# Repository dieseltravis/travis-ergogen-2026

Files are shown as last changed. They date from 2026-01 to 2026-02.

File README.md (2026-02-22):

# Travis's Ergogen v2026
This is a split keyboard with 2 ortholinear symmetrical 40-key halfs made with Ergogen v4. Multiple positions for an i2c OLED and mousewheel encoder. TRRS for connecting halfs, firmware not updated for that yet though.

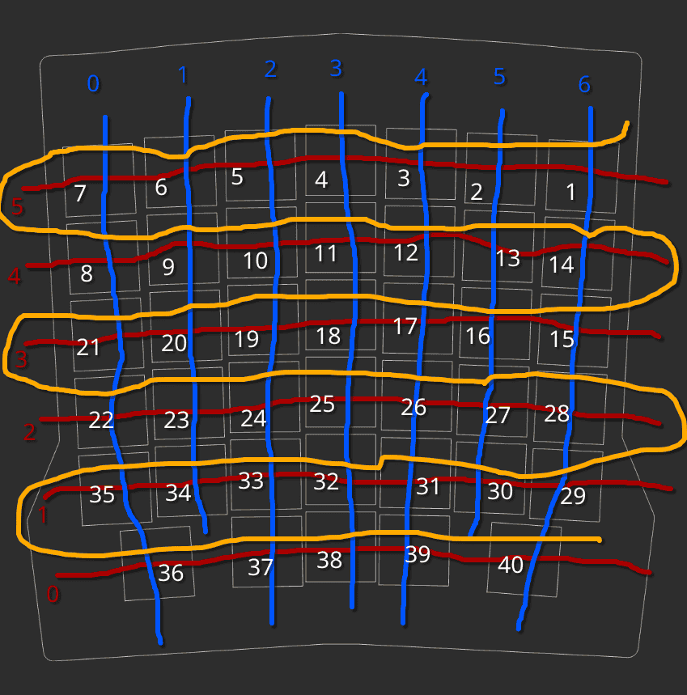
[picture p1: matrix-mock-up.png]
matrix mock up


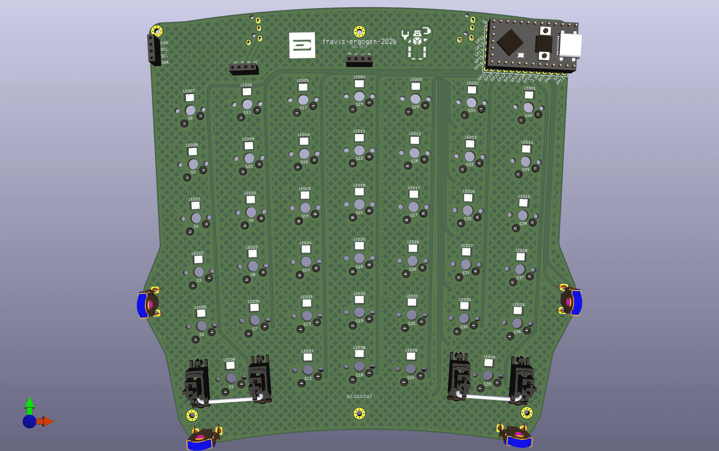
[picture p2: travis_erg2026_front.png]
PCB front


## Parts:

JLCPCB SMD components (40 each per board):
* capacitor C710467
* diode C7420318
* RGB LED C5378731
* MX C41430893

Other parts:
* MCU: RP2040 Community Edition
* capacitor 6.3V 1000uF
* resistors 510k ohm (2 per board)
* 2u stabilizers (2 per board)
* TRRS PJ-320A jacks (2 per board if connecting)
* mousewheel encoder (like Alps-EC10E1220501)
* OLED i2c
* MX switches (40 per board)
* low-profile sockets/pins for MCU & OLED

## References:
My previous ergogen abominations:
* [travis-ergogen-numpad](https://github.com/dieseltravis/travis-ergogen-numpad)
* [travis-ergogen-2024](https://github.com/dieseltravis/travis-ergogen-2024)

### Footprints:
* https://github.com/ceoloide/ergogen-footprints
* https://github.com/dieseltravis/ergogen-footprints-travis

## Tips:

### Font used:
```
brew install --cask font-3270-nerd-font
```
https://www.nerdfonts.com/font-downloads

### Routing widths used:
```
"track_widths": [
        0.0,
        0.254,
        0.3556,
        0.508,
        1.27
      ],
```

### For STL arcs
It is buggy, set toJscadScript's maxArcFacet in Ergogen's cases.js, example locations on my machine:
```
./node_modules/ergogen/src/cases.js
~/.local/share/mise/installs/node/24.13.0/lib/node_modules/ergogen/src/cases.js
```
Note: the arcs are *super* glitchy in STLs

### For weird `node\r:` error:
```
find ./node_modules/ -type f -print0 | xargs -0 dos2unix --
```

## TODO:
* ~board: make those weird bottom shapes nicer~
* plate: print a 2u stab test key
    * ~print a top key test to measure for interference with i2c~
* ~i2c: if plate doesn't interfere with bottom ones remove top ones~
    * ~trrs: if top ones are removed, move left trrs to left side~
* case: just use flat one, arcs get too glitchy
* ~routing~
* ~bom: use [kicad-jlcpcb-tools plugin](https://github.com/Bouni/kicad-jlcpcb-tools)~
* ~leds: generate positions~
* ~qmk firmware~
    * ~via support~
* then arrowpad

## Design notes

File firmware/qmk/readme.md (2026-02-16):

# dieseltravis/travis_ergogen_2026

dieseltravis/travis_ergogen_2026

* Keyboard Maintainer: [Travis Hardiman](https://github.com/dieseltravis)
* Hardware Supported: rp2040ce
* Hardware Availability: https://github.com/dieseltravis/travis-ergogen-2026

Make example for this keyboard (after setting up your build environment):

    make dieseltravis/travis_ergogen_2026:default

Flashing example for this keyboard:

    make dieseltravis/travis_ergogen_2026:default:flash

See the [build environment setup](https://docs.qmk.fm/#/getting_started_build_tools) and the [make instructions](https://docs.qmk.fm/#/getting_started_make_guide) for more information. Brand new to QMK? Start with our [Complete Newbs Guide](https://docs.qmk.fm/#/newbs).

## Bootloader

Enter the bootloader in 3 ways:

* **Bootmagic reset**: Hold down the key at (0,0) in the matrix (usually the top left key or Escape) and plug in the keyboard
* **Physical reset button**: Briefly press the button on the back of the PCB - some may have pads you must short instead
* **Keycode in layout**: Press the key mapped to `RESET` if it is available

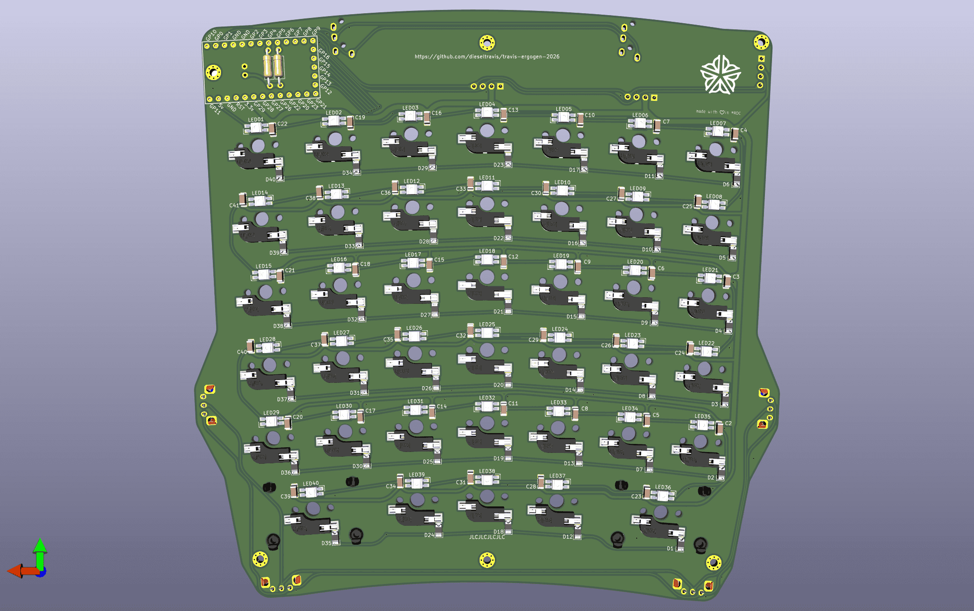
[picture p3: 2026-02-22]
travis_erg2026_back.png

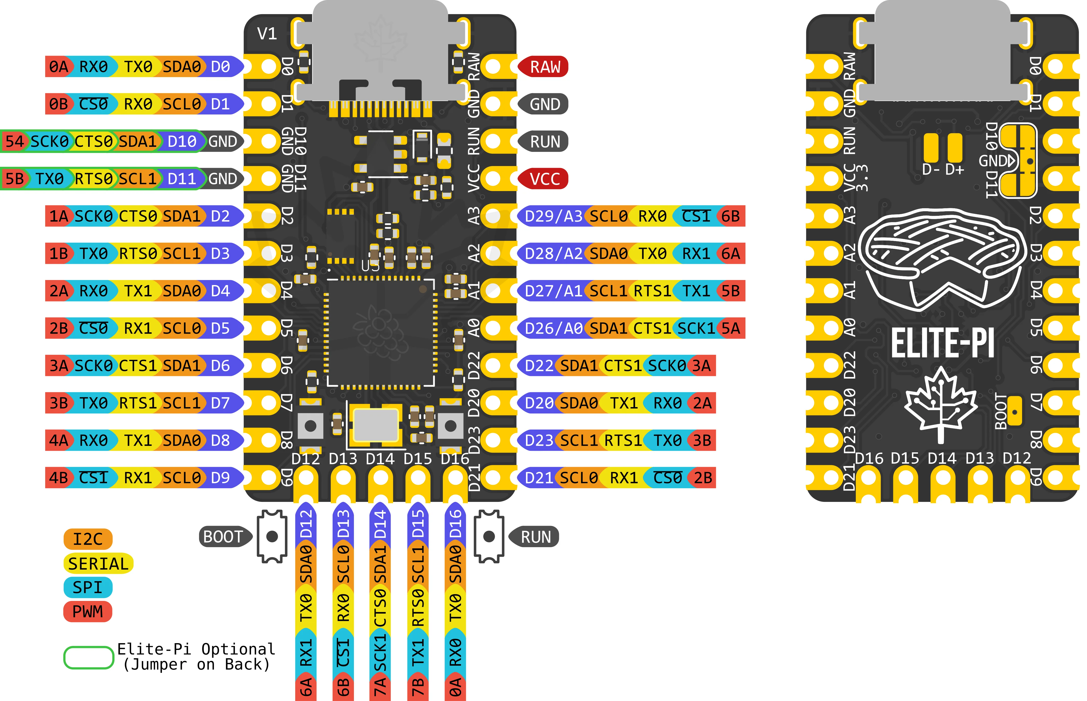
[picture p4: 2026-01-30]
datasheets/mcu-Elite-Pi.png

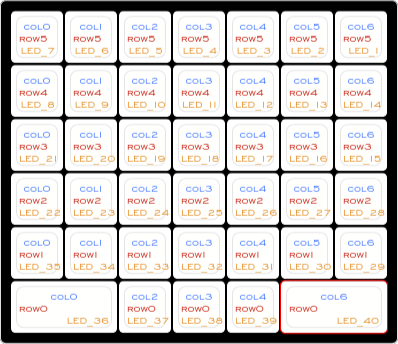
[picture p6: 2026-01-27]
kle/travis-ergogen-2026-matrix.png

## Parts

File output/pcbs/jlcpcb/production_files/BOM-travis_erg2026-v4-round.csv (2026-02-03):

Comment | Designator | Footprint | LCSC | Quantity
C41430893 | S1,S10,S11,S12,S13,S14,S15,S16,S17,S18,S19,S2,S20,S21,S22,S23,S24,S25,S26,S27,S28,S29,S3,S30,S31,S32,S33,S34,S35,S36,S37,S38,S39,S4,S40,S5,S6,S7,S8,S9 | switch_mx | C41430893 | 40
C5378731 | LED01,LED02,LED03,LED04,LED05,LED06,LED07,LED08,LED09,LED10,LED11,LED12,LED13,LED14,LED15,LED16,LED17,LED18,LED19,LED20,LED21,LED22,LED23,LED24,LED25,LED26,LED27,LED28,LED29,LED30,LED31,LED32,LED33,LED34,LED35,LED36,LED37,LED38,LED39,LED40 | led_SK6812mini-e (per-key, single-side) | C5378731 | 40
C710467 | C10,C11,C12,C13,C14,C15,C16,C17,C18,C19,C2,C20,C21,C22,C23,C24,C25,C26,C27,C28,C29,C3,C30,C31,C32,C33,C34,C35,C36,C37,C38,C39,C4,C40,C41,C5,C6,C7,C8,C9 | C_1206_3216Metric | C710467 | 40
C7420318 | D1,D10,D11,D12,D13,D14,D15,D16,D17,D18,D19,D2,D20,D21,D22,D23,D24,D25,D26,D27,D28,D29,D3,D30,D31,D32,D33,D34,D35,D36,D37,D38,D39,D4,D40,D5,D6,D7,D8,D9 | D_1206_3216Metric | C7420318 | 40

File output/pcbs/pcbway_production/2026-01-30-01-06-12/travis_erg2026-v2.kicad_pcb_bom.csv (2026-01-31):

Designator | Quantity | Value | Footprint | Package | MPN | DNP | Mount_Type
C1 | 1 | 6.3V 1000uF | C_Radial_D6.3mm_H11.0mm_P2.50mm |  |  |  | tht
C10, C11, C12, C13, C14, C15, C16, C17, C18, C19, C2, C20, C21, C22, C23, C24, C25, C26, C27, C28, C29, C3, C30, C31, C32, C33, C34, C35, C36, C37, C38, C39, C4, C40, C41, C5, C6, C7, C8, C9 | 40 | C710467 | C_1206_3216Metric |  |  |  | smt
D1, D10, D11, D12, D13, D14, D15, D16, D17, D18, D19, D2, D20, D21, D22, D23, D24, D25, D26, D27, D28, D29, D3, D30, D31, D32, D33, D34, D35, D36, D37, D38, D39, D4, D40, D5, D6, D7, D8, D9 | 40 | C7420318 | D_1206_3216Metric |  |  |  | smt
HOLE1, HOLE2, HOLE3, HOLE4, HOLE5, HOLE6 | 6 |  | MountingHole_2.2mm_M2_Pad_Via |  |  |  | tht
LED01, LED02, LED03, LED04, LED05, LED06, LED07, LED08, LED09, LED10, LED11, LED12, LED13, LED14, LED15, LED16, LED17, LED18, LED19, LED20, LED21, LED22, LED23, LED24, LED25, LED26, LED27, LED28, LED29, LED30, LED31, LED32, LED33, LED34, LED35, LED36, LED37, LED38, LED39, LED40 | 40 | C5378731 | led_SK6812mini-e (per-key, single-side) |  |  |  | smt
MCU1 | 1 | RP2040 Community Edition | RP2040_Pro_Micro |  |  |  | tht
OLED1, OLED2, OLED3, OLED4, OLED5 | 5 | I2C_Breakout | I2C_Breakout |  |  |  | tht
ROT1, ROT2, ROT3, ROT4 | 4 | EC10E1220501 | Alps-EC10E1220501 |  |  |  | tht
S1, S10, S11, S12, S13, S14, S15, S16, S17, S18, S19, S2, S20, S21, S22, S23, S24, S25, S26, S27, S28, S29, S3, S30, S31, S32, S33, S34, S35, S36, S37, S38, S39, S4, S40, S5, S6, S7, S8, S9 | 40 | C41430893 | switch_mx |  |  |  | smt

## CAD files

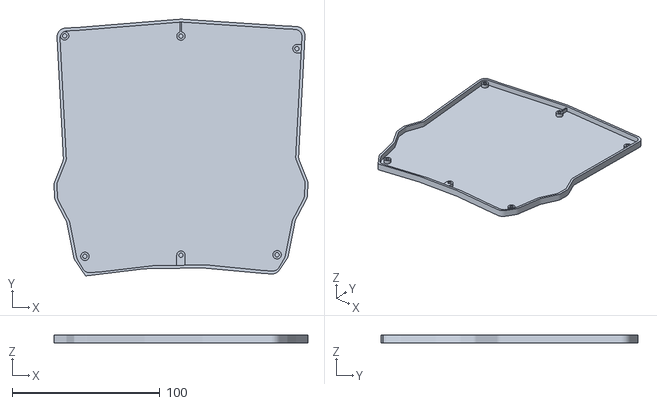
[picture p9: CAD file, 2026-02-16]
output/cases/case.stl
172.1 x 174.0 x 5.60

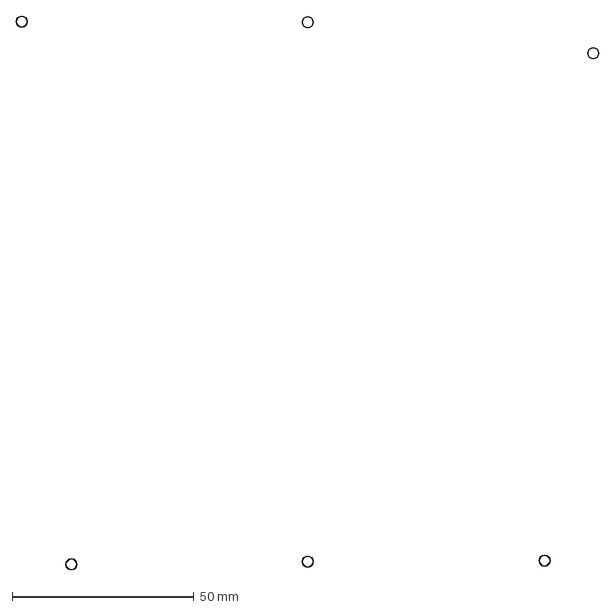
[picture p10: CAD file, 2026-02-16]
output/outlines/_mounting.dxf
160.3 x 152.4 mm

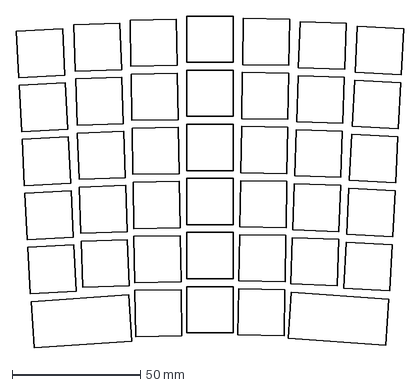
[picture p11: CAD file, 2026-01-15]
output/points/demo.dxf
150.7 x 129.1 mm

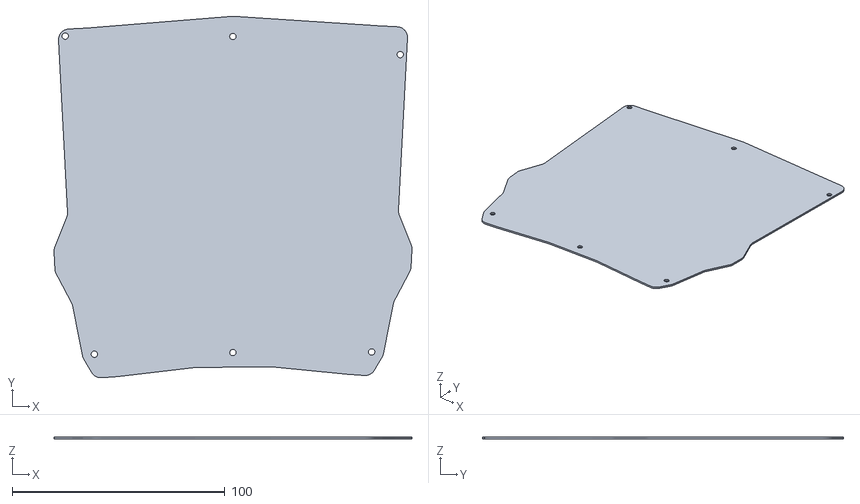
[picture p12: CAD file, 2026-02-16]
output/cases/flatcase.stl
168.1 x 169.8 x 1.00

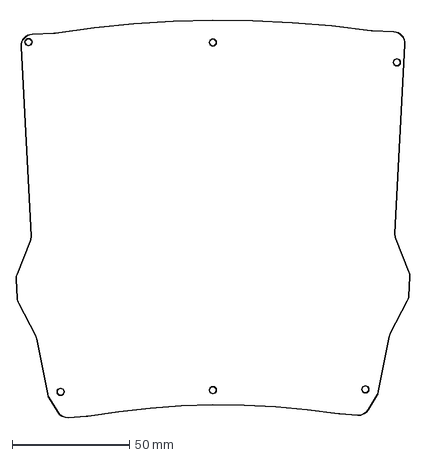
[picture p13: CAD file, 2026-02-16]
output/outlines/flat.dxf
168.2 x 171.7 mm

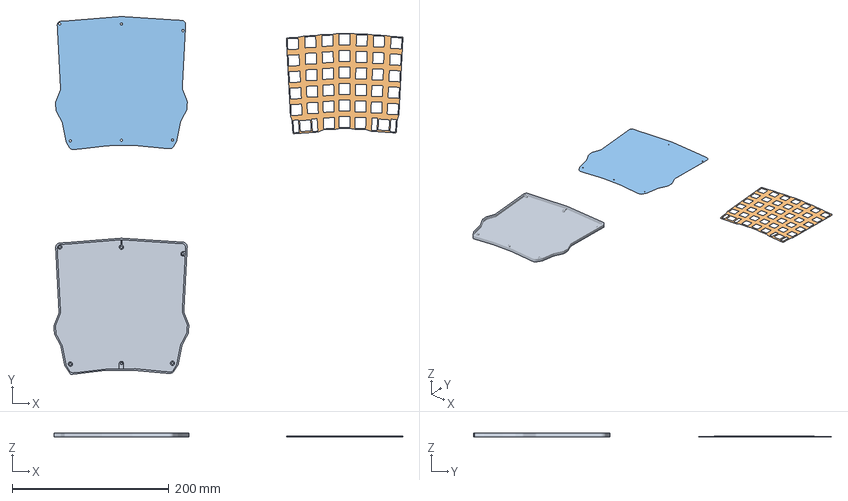
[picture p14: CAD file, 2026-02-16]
output/cases/cases.3mf
445.3 x 456.8 x 5.60 mm
case.stl
plate.stl
flatcase.stl

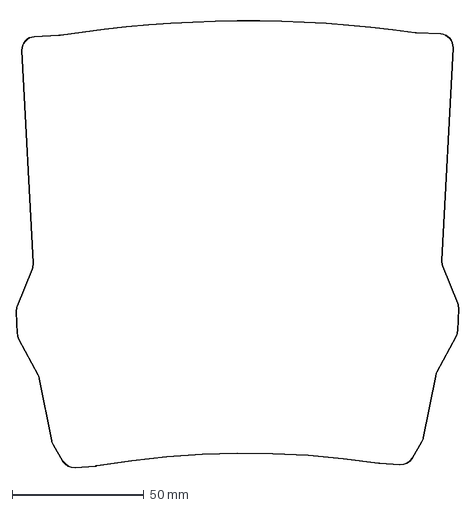
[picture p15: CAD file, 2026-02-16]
output/outlines/board.dxf
168.2 x 171.7 mm

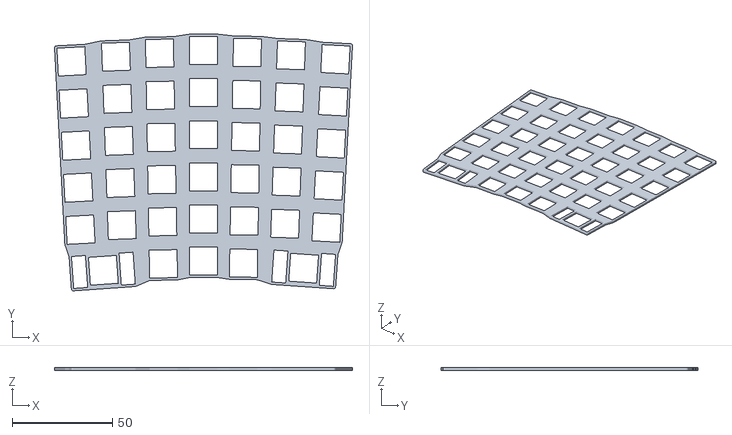
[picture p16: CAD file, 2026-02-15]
output/cases/plate.stl
148.9 x 128.3 x 1.41

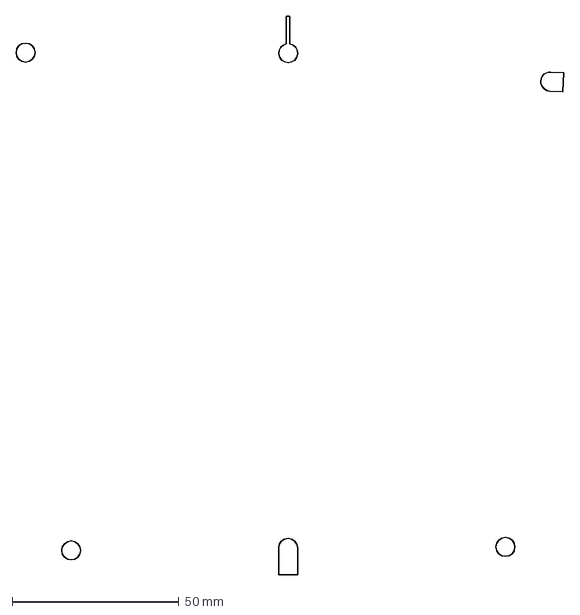
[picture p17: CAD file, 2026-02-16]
output/outlines/_standoff.dxf
164.3 x 167.4 mm

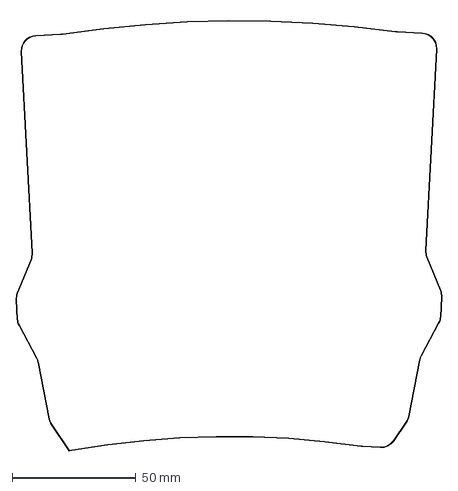
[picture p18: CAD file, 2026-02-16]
output/outlines/_xlboard.dxf
172.2 x 175.8 mm

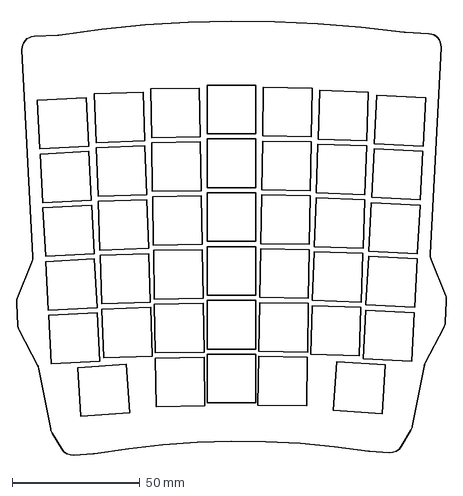
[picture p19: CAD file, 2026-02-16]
output/outlines/_combo.dxf
168.2 x 171.7 mm

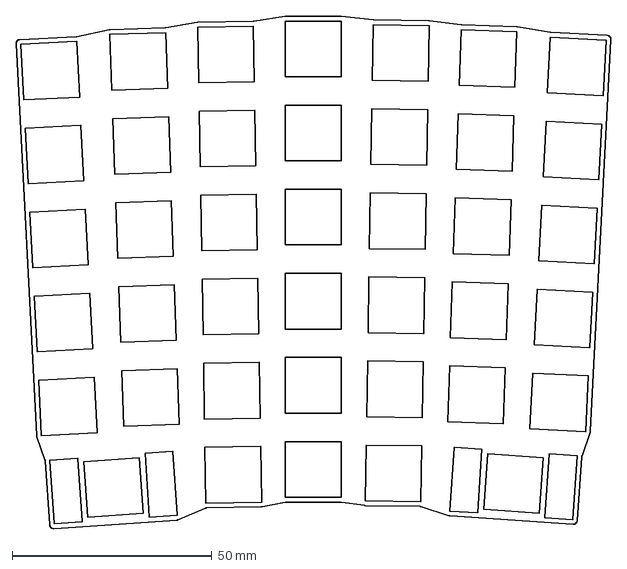
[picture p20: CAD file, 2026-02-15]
output/outlines/_plateholes.dxf
149.0 x 128.3 mm

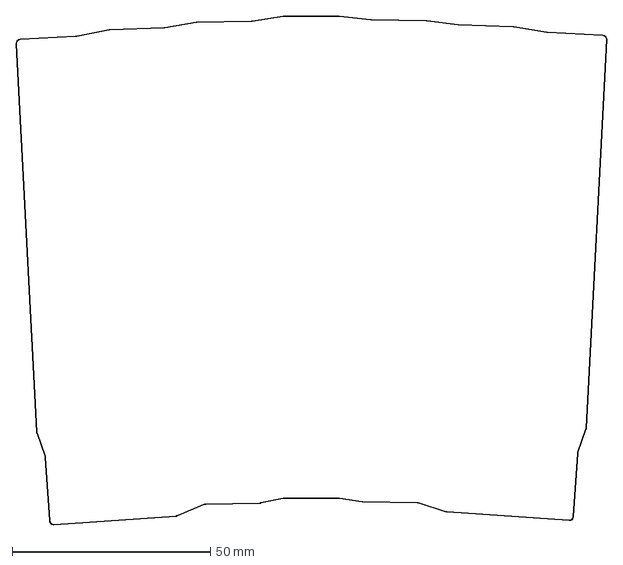
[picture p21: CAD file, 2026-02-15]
output/outlines/_pb.dxf
149.0 x 128.3 mm

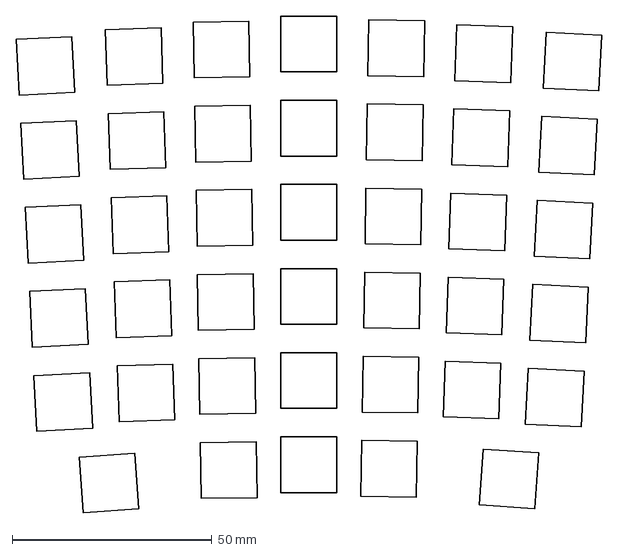
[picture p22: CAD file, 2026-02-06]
output/outlines/_keyholes.dxf
146.5 x 124.2 mm

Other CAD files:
output/outlines/_2u_stabilizer.dxf
output/outlines/_keys.dxf
output/outlines/combo.dxf
output/outlines/mounting.dxf
output/outlines/standoff.dxf
output/outlines/xlboard.dxf

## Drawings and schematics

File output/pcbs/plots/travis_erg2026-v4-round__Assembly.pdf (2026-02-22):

1 | 2 | 3 | 4 | 5 | 6 | 7 | 8

A

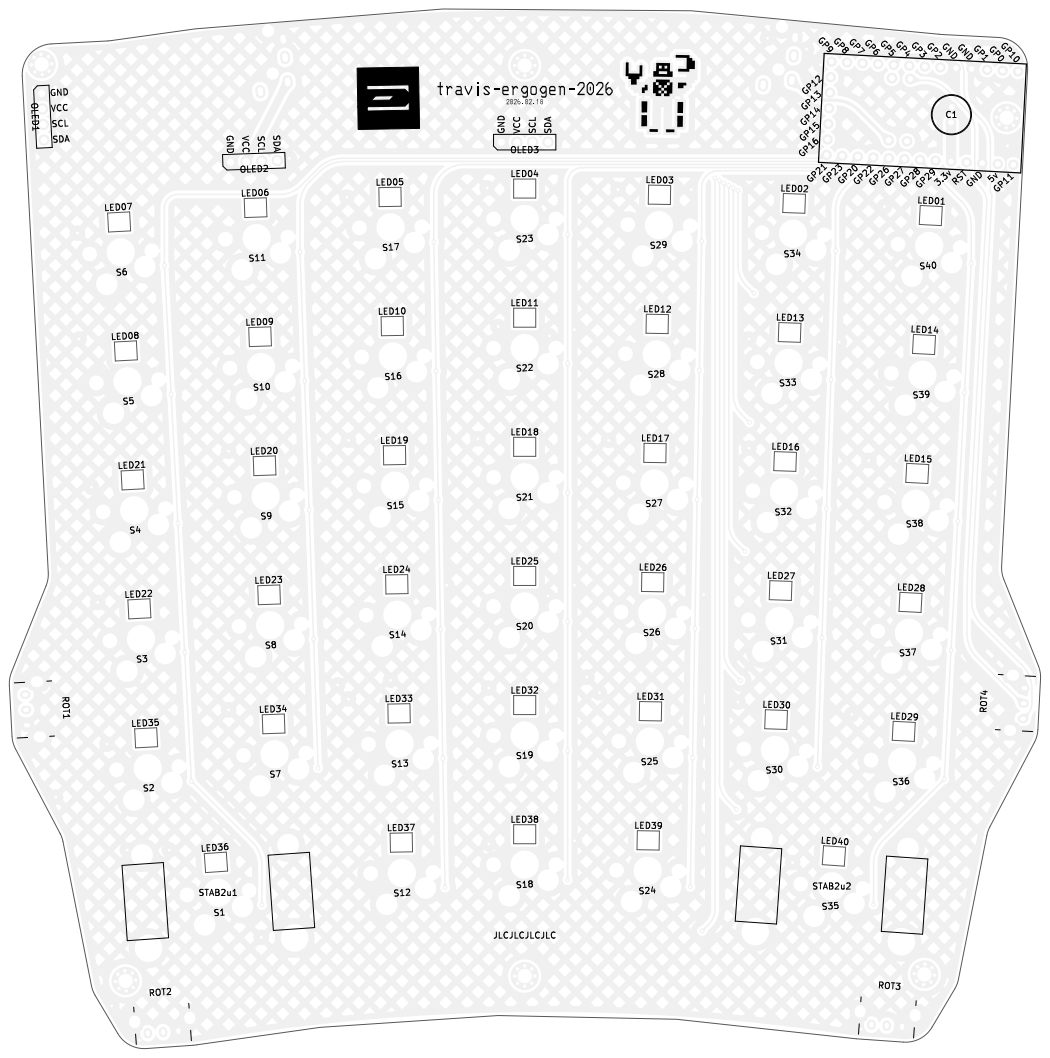
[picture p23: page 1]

SCL SDA GND VCC SCL SDAGND VCC SCL SDA

File: travis_erg2026-v4-round.kicad_pcb Sheet: Black And White TOP
Id: /1 Title: travis_erg2026

1 | 2 | 3 | 4 | 5 | 6 | 7 | 8

A

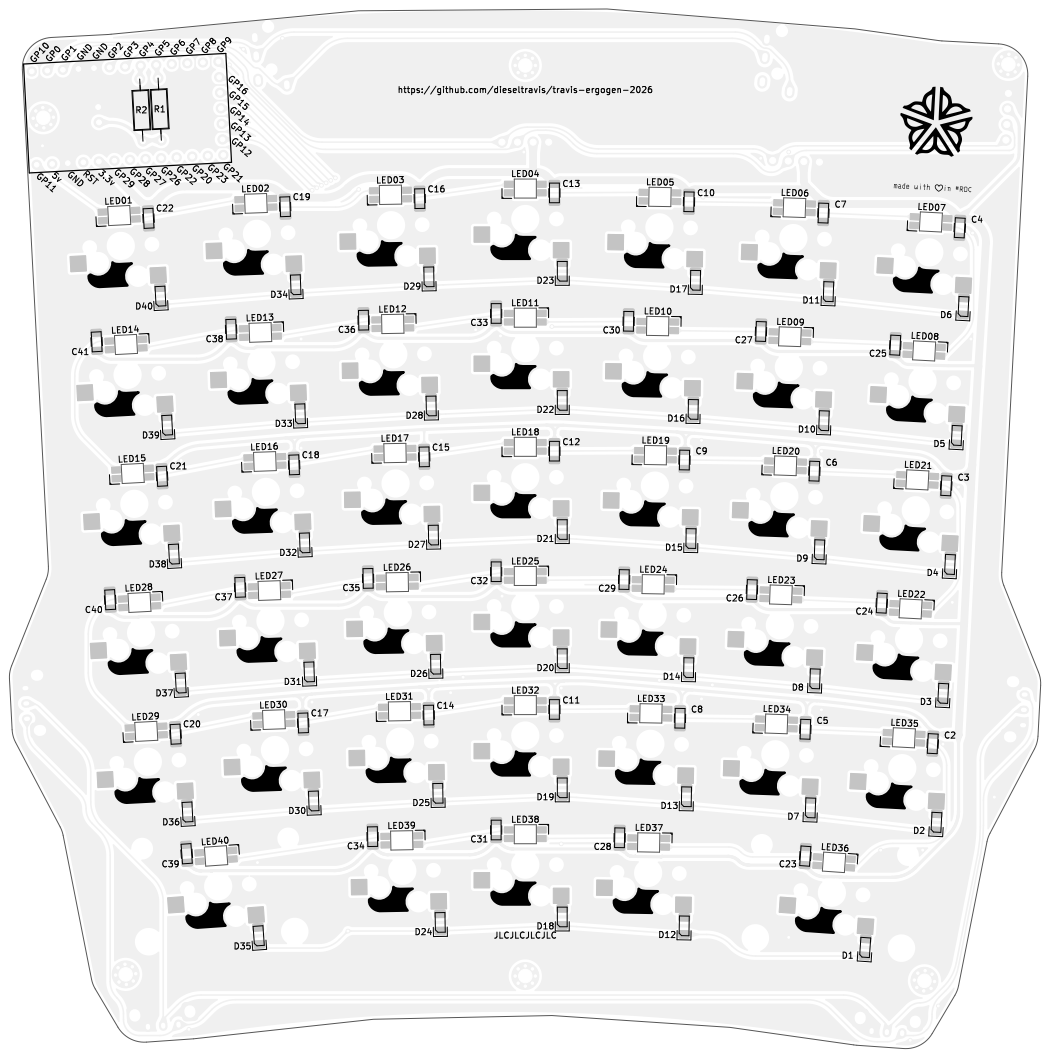
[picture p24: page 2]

https://github.com/dieseltravis/travis-ergogen-2026

File: travis_erg2026-v4-round.kicad_pcb Sheet: Black And White BOT
Id: /1 Title: travis_erg2026

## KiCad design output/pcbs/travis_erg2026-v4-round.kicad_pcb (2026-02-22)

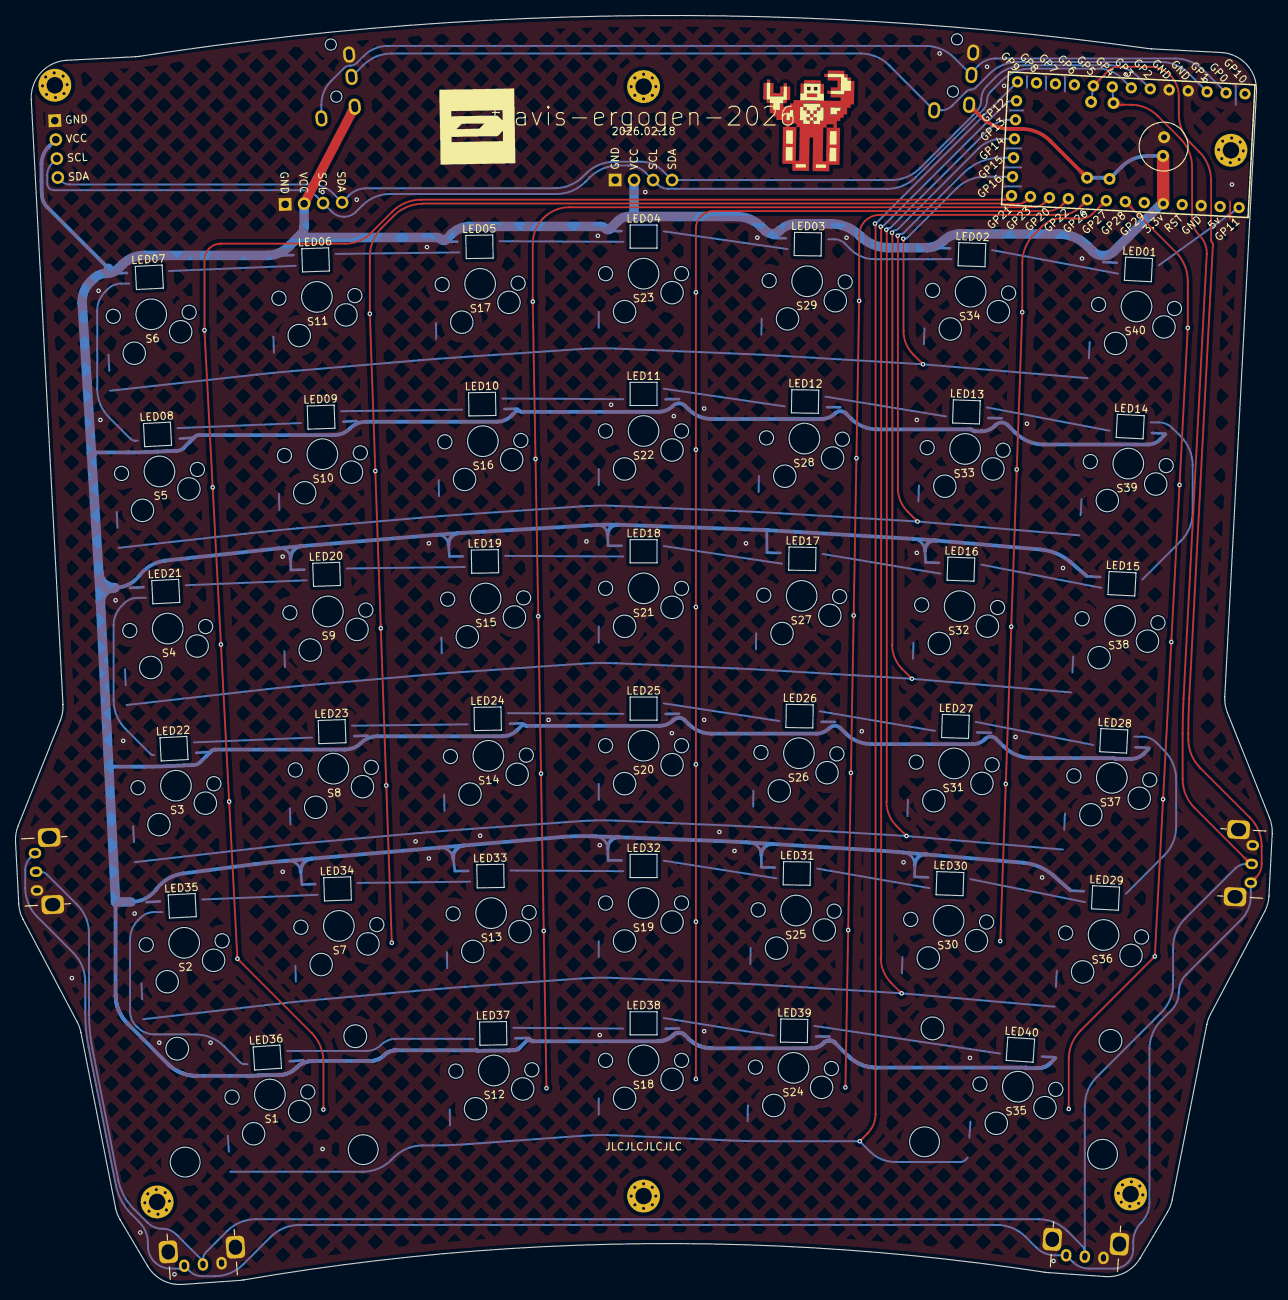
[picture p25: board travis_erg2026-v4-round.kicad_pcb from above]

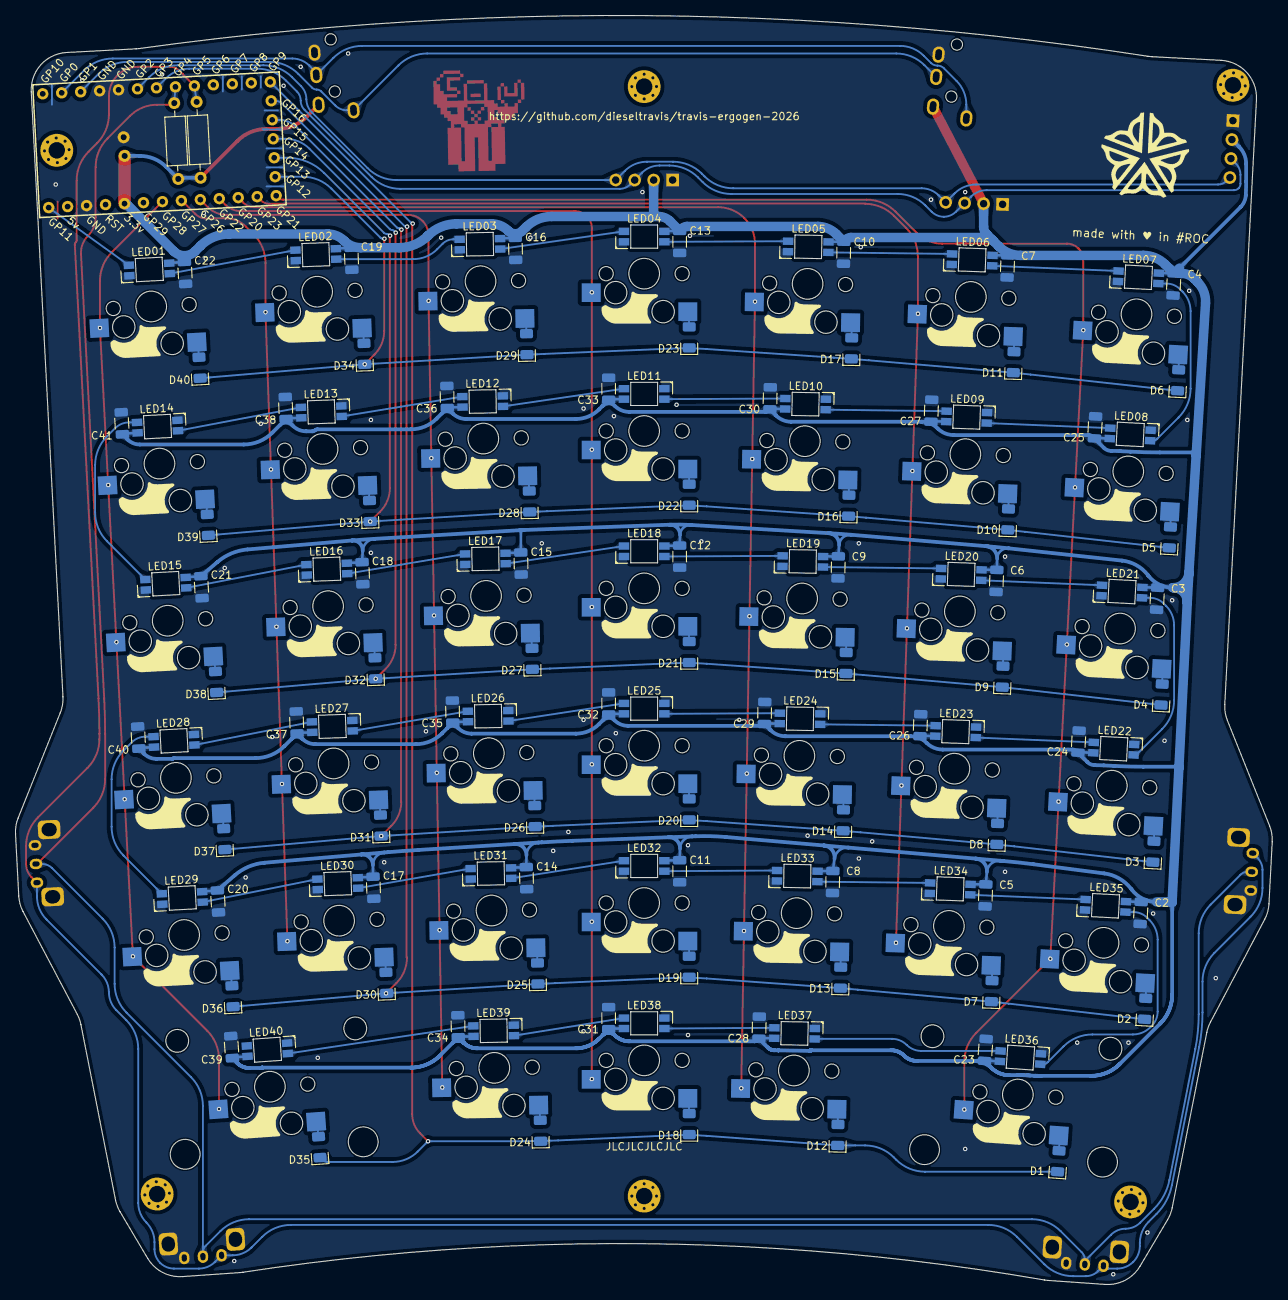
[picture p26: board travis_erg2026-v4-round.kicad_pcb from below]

Board: 2 copper layers, 168.1 x 169.8 mm, 184 parts (163 on the bottom side), 101 nets.

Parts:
C1: 6.3V 1000uF; C_Radial_D6.3mm_H11.0mm_P2.50mm
C2, C3, C4, C5, C6, C7, C8, C9, C10, C11, C12, C13, C14, C15, C16, C17, C18, C19, C20, C21, C22, C23, C24, C25, C26, C27, C28, C29, C30, C31, C32, C33, C34, C35, C36, C37, C38, C39, C40, C41: C710467; C_1206_3216Metric
D1, D2, D3, D4, D5, D6, D7, D8, D9, D10, D11, D12, D13, D14, D15, D16, D17, D18, D19, D20, D21, D22, D23, D24, D25, D26, D27, D28, D29, D30, D31, D32, D33, D34, D35, D36, D37, D38, D39, D40: C7420318; D_1206_3216Metric
HOLE1, HOLE2, HOLE3, HOLE4, HOLE5, HOLE6: MountingHole_2.2mm_M2_Pad_Via
LED01, LED02, LED03, LED04, LED05, LED06, LED07, LED08, LED09, LED10, LED11, LED12, LED13, LED14, LED15, LED16, LED17, LED18, LED19, LED20, LED21, LED22, LED23, LED24, LED25, LED26, LED27, LED28, LED29, LED30, LED31, LED32, LED33, LED34, LED35, LED36, LED37, LED38, LED39, LED40: C5378731; led_SK6812mini-e (per-key, single-side)
LOGO1: utility_ergogen_logo
LOGO2: travis
MCU1: RP2040 Community Edition; RP2040_Pro_Micro
OLED1, OLED2, OLED3: I2C_Breakout
R1, R2: 510k; R_Axial_DIN0207_L6.3mm_D2.5mm_P10.16mm_Horizontal
ROC1: travis
ROT1, ROT2, ROT3, ROT4: EC10E1220501; Alps-EC10E1220501
S1, S2, S3, S4, S5, S6, S7, S8, S9, S10, S11, S12, S13, S14, S15, S16, S17, S18, S19, S20, S21, S22, S23, S24, S25, S26, S27, S28, S29, S30, S31, S32, S33, S34, S35, S36, S37, S38, S39, S40: C41430893; switch_mx
STAB2u1, STAB2u2: Stabilizer_MX_2.00u
TRRS1, TRRS2: trrs_pj320a

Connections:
GND: C1.2, C2.2, C3.2, C4.2, C5.2, C6.2, C7.2, C8.2, C9.2, C10.2, C11.2, C12.2, C13.2, C14.2, C15.2, C16.2, C17.2, C18.2, C19.2, C20.2, C21.2, C22.2, C23.2, C24.2, C25.2, C26.2, C27.2, C28.2, C29.2, C30.2, C31.2, C32.2, C33.2, C34.2, C35.2, C36.2, C37.2, C38.2, C39.2, C40.2, C41.2, LED01.3, LED02.3, LED03.3, LED04.3, LED05.3, LED06.3, LED07.3, LED08.3, LED09.3, LED10.3, LED11.3, LED12.3, LED13.3, LED14.3, LED15.3, LED16.3, LED17.3, LED18.3, LED19.3, LED20.3, LED21.3, LED22.3, LED23.3, LED24.3, LED25.3, LED26.3, LED27.3, LED28.3, LED29.3, LED30.3, LED31.3, LED32.3, LED33.3, LED34.3, LED35.3, LED36.3, LED37.3, LED38.3, LED39.3, LED40.3, MCU1.4, MCU1.5, MCU1.29, OLED1.1, OLED2.1, OLED3.1, ROT1.4, ROT1.C, ROT2.4, ROT2.C, ROT3.4, ROT3.C, ROT4.4, ROT4.C, TRRS1.2, TRRS2.2
LED01: LED01.4, MCU1.31
LED02: LED01.2, LED02.4
LED03: LED02.2, LED03.4
LED04: LED03.2, LED04.4
LED05: LED04.2, LED05.4
LED06: LED05.2, LED06.4
LED07: LED06.2, LED07.4
LED08: LED07.2, LED08.4
LED09: LED08.2, LED09.4
LED10: LED09.2, LED10.4
LED11: LED10.2, LED11.4
LED12: LED11.2, LED12.4
LED13: LED12.2, LED13.4
LED14: LED13.2, LED14.4
LED15: LED14.2, LED15.4
LED16: LED15.2, LED16.4
LED17: LED16.2, LED17.4
LED18: LED17.2, LED18.4
LED19: LED18.2, LED19.4
LED20: LED19.2, LED20.4
LED21: LED20.2, LED21.4
LED22: LED21.2, LED22.4
LED23: LED22.2, LED23.4
LED24: LED23.2, LED24.4
LED25: LED24.2, LED25.4
LED26: LED25.2, LED26.4
LED27: LED26.2, LED27.4
LED28: LED27.2, LED28.4
LED29: LED28.2, LED29.4
LED30: LED29.2, LED30.4
LED31: LED30.2, LED31.4
LED32: LED31.2, LED32.4
LED33: LED32.2, LED33.4
LED34: LED33.2, LED34.4
LED35: LED34.2, LED35.4
LED36: LED35.2, LED36.4
LED37: LED36.2, LED37.4
LED38: LED37.2, LED38.4
LED39: LED38.2, LED39.4
LED40: LED39.2, LED40.4
RX: MCU1.3, TRRS1.3, TRRS2.5
TX: MCU1.2, TRRS1.5, TRRS2.3
VCC: C1.1, C2.1, C3.1, C4.1, C5.1, C6.1, C7.1, C8.1, C9.1, C10.1, C11.1, C12.1, C13.1, C14.1, C15.1, C16.1, C17.1, C18.1, C19.1, C20.1, C21.1, C22.1, C23.1, C24.1, C25.1, C26.1, C27.1, C28.1, C29.1, C30.1, C31.1, C32.1, C33.1, C34.1, C35.1, C36.1, C37.1, C38.1, C39.1, C40.1, C41.1, LED01.1, LED02.1, LED03.1, LED04.1, LED05.1, LED06.1, LED07.1, LED08.1, LED09.1, LED10.1, LED11.1, LED12.1, LED13.1, LED14.1, LED15.1, LED16.1, LED17.1, LED18.1, LED19.1, LED20.1, LED21.1, LED22.1, LED23.1, LED24.1, LED25.1, LED26.1, LED27.1, LED28.1, LED29.1, LED30.1, LED31.1, LED32.1, LED33.1, LED34.1, LED35.1, LED36.1, LED37.1, LED38.1, LED39.1, LED40.1, MCU1.27, OLED1.2, OLED2.2, OLED3.2, R1.1, R2.1, TRRS1.4, TRRS2.4
col0: MCU1.19, S1.1, S2.1, S3.1, S4.1, S5.1, S6.1
col1: MCU1.20, S7.1, S8.1, S9.1, S10.1, S11.1
col2: MCU1.21, S12.1, S13.1, S14.1, S15.1, S16.1, S17.1
col3: MCU1.22, S18.1, S19.1, S20.1, S21.1, S22.1, S23.1
col4: MCU1.23, S24.1, S25.1, S26.1, S27.1, S28.1, S29.1
col5: MCU1.24, S30.1, S31.1, S32.1, S33.1, S34.1
col6: MCU1.25, S35.1, S36.1, S37.1, S38.1, S39.1, S40.1
encA: MCU1.9, R1.2, ROT1.A, ROT2.A, ROT3.A, ROT4.A
encB: MCU1.8, R2.2, ROT1.B, ROT2.B, ROT3.B, ROT4.B
matrix_col0_row0: D1.2, S1.2
matrix_col0_row1: D2.2, S2.2
matrix_col0_row2: D3.2, S3.2
matrix_col0_row3: D4.2, S4.2
matrix_col0_row4: D5.2, S5.2
matrix_col0_row5: D6.2, S6.2
matrix_col1_row1: D7.2, S7.2
matrix_col1_row2: D8.2, S8.2
matrix_col1_row3: D9.2, S9.2
matrix_col1_row4: D10.2, S10.2
matrix_col1_row5: D11.2, S11.2
matrix_col2_row0: D12.2, S12.2
matrix_col2_row1: D13.2, S13.2
matrix_col2_row2: D14.2, S14.2
matrix_col2_row3: D15.2, S15.2
matrix_col2_row4: D16.2, S16.2
matrix_col2_row5: D17.2, S17.2
matrix_col3_row0: D18.2, S18.2
matrix_col3_row1: D19.2, S19.2
matrix_col3_row2: D20.2, S20.2
matrix_col3_row3: D21.2, S21.2
matrix_col3_row4: D22.2, S22.2
matrix_col3_row5: D23.2, S23.2
matrix_col4_row0: D24.2, S24.2
matrix_col4_row1: D25.2, S25.2
matrix_col4_row2: D26.2, S26.2
matrix_col4_row3: D27.2, S27.2
matrix_col4_row4: D28.2, S28.2
matrix_col4_row5: D29.2, S29.2
matrix_col5_row1: D30.2, S30.2
matrix_col5_row2: D31.2, S31.2
matrix_col5_row3: D32.2, S32.2
matrix_col5_row4: D33.2, S33.2
matrix_col5_row5: D34.2, S34.2
matrix_col6_row0: D35.2, S35.2
matrix_col6_row1: D36.2, S36.2
matrix_col6_row2: D37.2, S37.2
matrix_col6_row3: D38.2, S38.2
matrix_col6_row4: D39.2, S39.2
matrix_col6_row5: D40.2, S40.2
row0: D1.1, D12.1, D18.1, D24.1, D35.1, MCU1.13
row1: D2.1, D7.1, D13.1, D19.1, D25.1, D30.1, D36.1, MCU1.14
row2: D3.1, D8.1, D14.1, D20.1, D26.1, D31.1, D37.1, MCU1.15
row3: D4.1, D9.1, D15.1, D21.1, D27.1, D32.1, D38.1, MCU1.16
row4: D5.1, D10.1, D16.1, D22.1, D28.1, D33.1, D39.1, MCU1.17
row5: D6.1, D11.1, D17.1, D23.1, D29.1, D34.1, D40.1, MCU1.18
scl: MCU1.7, OLED1.3, OLED2.3, OLED3.3
sda: MCU1.6, OLED1.4, OLED2.4, OLED3.4

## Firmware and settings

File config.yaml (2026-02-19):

meta:
  engine: 4.2.1
  name: &name "travis-ergogen-2026"
  version: &meta_version "2026.02.18"
  date: "2026-02-18"
  author: 'Travis Hardiman'
  url: &url https://github.com/dieseltravis/travis-ergogen-2026
  tags: [ "ergogen", "keyboard", "cherrymx", "hotswap", "rp2040", "rp2040ce", "wheel", "oled" ]
  # https://www.nerdfonts.com/font-downloads
  cool_font: &cool_font "3270 Nerd Font"
units:
  kp: U + 2
  kspr: U + 1
  bp: kp/2 + 4
  sp: 1
  st: 1
  # stabs
  stabilizer_width: 7
  stabilizer_height: 16
  stabilizer_offset: 0 # This means south stabs, use `orient` to rotate them for north facing scenarios
  stabilizer_spacing_2u: 23.86 / 2 # 0.94in / 2
  # M2 Screw Inserts
  screwSize: 1.5
  standoffSize: 2.85
  # case
  board: 1.6
  height: 4.0
  wall: 2.0
  casethick: 1
  platehole: 13.95
  platethick: 1.41
  plate2uw: stabilizer_spacing_2u + stabilizer_width/2
  platew: 1.20
points:
  zones:
    matrix:
      anchor:
        # move the PCB into view for KiCad
        shift: [50, -200]
      key:
        padding: kp
        spread: kspr
        #splay: 0
        tags:
          - key
      columns:
        col0:
          key:
            tags: col_even
            splay: 3sp
            stagger: 0st
            column_net: col0
          rows:
            row0:
              shift: [0.5kspr, 0.0kp]
              width: 2U
              rotate: 1
              tags:
                - row_even
                - key
                - 2u_stabs
              key:
                led_next: LED37
                led_this: LED36
            row1:
              shift: [-0.5kspr, 0.0kp]
              rotate: -1
              key:
                led_next: LED36
                led_this: LED35
            row2:
              key:
                led_next: LED23
                led_this: LED22
            row3:
              key:
                led_next: LED22
                led_this: LED21
            row4:
              key:
                led_next: LED09
                led_this: LED08
            row5:
              key:
                led_next: LED08
                led_this: LED07
        col1:
          key:
            tags: col_odd
            splay: -sp
            stagger: st
            column_net: col1
          rows:
            row0:
              skip: true
              #key:
              #  led_next: LED38
              #  led_this: LED37
            row1:
              key:
                led_next: LED35
                led_this: LED34
            row2:
              key:
                led_next: LED24
                led_this: LED23
            row3:
              key:
                led_next: LED21
                led_this: LED20
            row4:
              key:
                led_next: LED10
                led_this: LED09
            row5:
              key:
                led_next: LED07
                led_this: LED06
        col2:
          key:
            tags: col_even
            splay: -sp
            stagger: st
            column_net: col2
          rows:
            row0:
              key:
                #led_next: LED39
                #led_this: LED38
                led_next: LED38
                led_this: LED37
            row1:
              key:
                led_next: LED34
                led_this: LED33
            row2:
              key:
                led_next: LED25
                led_this: LED24
            row3:
              key:
                led_next: LED20
                led_this: LED19
            row4:
              key:
                led_next: LED11
                led_this: LED10
            row5:
              key:
                led_next: LED06
                led_this: LED05
        col3:
          key:
            tags: col_odd
            splay: -sp
            stagger: st
            column_net: col3
          rows:
            row0:
              key:
                #led_next: LED40
                #led_this: LED39
                led_next: LED39
                led_this: LED38
            row1:
              key:
                led_next: LED33
                led_this: LED32
            row2:
              key:
                led_next: LED26
                led_this: LED25
            row3:
              key:
                led_next: LED19
                led_this: LED18
            row4:
              key:
                led_next: LED12
                led_this: LED11
            row5:
              key:
                led_next: LED05
                led_this: LED04
        col4:
          key:
            tags: col_even
            splay: -sp
            stagger: -st
            column_net: col4
          rows:
            row0:
              key:
                #led_next: LED41
                #led_this: LED40
                led_next: LED40
                led_this: LED39
            row1:
              key:
                led_next: LED32
                led_this: LED31
            row2:
              key:
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

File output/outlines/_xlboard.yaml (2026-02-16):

models:
    export:
        models:
            a:
                models: {}
                origin:
                    - 0
                    - 0
            b:
                models:
                    path1:
                        paths:
                            ShapeLine1:
                                type: line
                                origin:
                                    - 178.11803031288437
                                    - -57.5818771443103
                                end:
                                    - 188.3714739681991
                                    - -58.11923736938954
                            ShapeLine2:
                                type: line
                                origin:
                                    - 194.04923514234085
                                    - -64.42503056279384
                                end:
                                    - 189.7665854065865
                                    - -146.14285376700263
                            ShapeLine3:
                                type: line
                                origin:
                                    - 190.18804672823907
                                    - -148.68657412144296
                                end:
                                    - 195.67069556144057
                                    - -162.38349435277433
                            ShapeLine4:
                                type: line
                                origin:
                                    - 196.0921568883197
                                    - -164.92721470748847
                                end:
                                    - 195.6794910804426
                                    - -172.80134648856347
                            ShapeLine5:
                                type: line
                                origin:
                                    - 194.9944473762618
                                    - -175.28707681789012
                                end:
                                    - 187.9040914525441
                                    - -188.72637505290749
                            ShapeLine6:
                                type: line
                                origin:
                                    - 187.32418955634412
                                    - -190.36529239588288
                                end:
                                    - 182.79128464930542
                                    - -213.35193386363596
                            ShapeLine7:
                                type: line
                                origin:
                                    - 181.85855720462706
                                    - -215.57618916054236
                                end:
                                    - 176.64893927736887
                                    - -223.20021462628216
                            ShapeLine8:
                                type: line
                                origin:
                                    - 171.27649236287797
                                    - -225.80051462066126
                                end:
                                    - 163.95676746530214
                                    - -225.28866960393046
                        origin:
                            - 0
                            - 0
                    path3:
                        paths:
                            ShapeLine1:
                                type: line
                                origin:
                                    - 46.3743697
                                    - -227.01868770000002
                                end:
                                    - 45.3768056
                                    - -227.0884442
                            ShapeLine2:
                                type: line
                                origin:
                                    - 45.3768056
                                    - -227.0884442
                                end:
                                    - 38.22638989537296
                                    - -216.62415446054234
                            ShapeLine3:
                                type: line
                                origin:
                                    - 37.29366245069454
                                    - -214.39989916363578
                                end:
                                    - 32.760757543655885
                                    - -191.41325769588295
                            ShapeLine4:
                                type: line
                                origin:
                                    - 32.18085564745599
                                    - -189.77434035290764
                                end:
                                    - 25.090499723738212
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

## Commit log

2025-11-09 pcb generation
    [board.dxf, combo.dxf, demo.dxf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]
2026-01-18 led caps
    [board.dxf, combo.dxf, row_even.dxf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]
2026-01-18 stabs, diodes, caps labels
    [2u_stabilizer.dxf, travis_erg2026.kicad_pcb]
2026-01-19 holes, oled options
    [board.dxf, combo.dxf, travis_erg2026.kicad_pcb]
2026-01-19 scotto keebs 2040 promicro
    [travis_erg2026.kicad_pcb]
2026-01-19 adjusted to fit
    [travis_erg2026.kicad_pcb]
2026-01-21 Update footprint submodule
2026-01-21 Remove footprint submodule
2026-01-21 update modules
    [travis_erg2026.kicad_pcb]
2026-01-21 travis footprints submodule
2026-01-21 testing footprints
    [travis_erg2026.kicad_pcb]
2026-01-23 update board with room and i2c headers
    [board.dxf, combo.dxf, travis_erg2026.kicad_pcb]
2026-01-24 board updates, hole updates
    [board.dxf, combo.dxf, travis_erg2026.kicad_pcb]
2026-01-24 footprint updates, wheels, holes
    [board.dxf, combo.dxf, travis_erg2026.kicad_pcb]
2026-01-24 minor updates
    [travis_erg2026.kicad_pcb]
2026-01-24 update mounting
    [_holes.stl, _innerwall.stl, _outerwall.stl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]
2026-01-24 case standoff adjustments
    [_standoffs.stl, case.stl, standoff.dxf]
2026-01-25 refinements for kicad
2026-01-26 bunch of documentation
    [travis_erg2026-v1-B_Cu.gbr, travis_erg2026-v1-B_Mask.gbr, travis_erg2026-v1-B_Paste.gbr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]
2026-01-27 BOM and CPL progress
    [travis-ergogen-2026-BOM_JLCSMT.csv, travis_erg2026-bom.csv, travis_erg2026.kicad_pcb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]
2026-01-30 attempt 2
    [bom.csv, designators.csv, positions.csv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]
2026-01-31 v2 wired
    [bom.csv, designators.csv, positions.csv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]
2026-01-31 rounded version
    [travis_erg2026-v2-round.kicad_pcb, travis_erg2026-v2.kicad_pcb, travis_erg2026-v2.step]
2026-02-01 fix encorder, organize datasheets, add easy routes and vias
    [bom.csv, positions.csv, travis_erg2026-v2-round.kicad_pcb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]
2026-02-03 v3 routed
    [bom.csv, designators.csv, positions.csv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]
2026-02-03 jlc pcb bom and pos
    [BOM-travis_erg2026-v3-round.csv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]
2026-02-08 trrs, corners
    [board.dxf, combo.dxf, travis_erg2026-v3-round.kicad_pcb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]
2026-02-08 footprint updates
2026-02-10 trrs data sheet
    [_innerwall.stl, bottom.stl, case.stl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]
2026-02-13 arcs are messed up
    [_holes.stl, _innerwall.stl, _outerwall.stl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]
2026-02-13 yarn upgrade and arcs in progress
    [_holes.stl, _innerwall.stl, _outerwall.stl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]
2026-02-15 plate refinements
    [pb.dxf, plate.stl, plateholes.dxf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]
2026-02-16 board outline update, qmk start
    [_2u_stabilizer.dxf, _combo.dxf, _keyholes.dxf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]
2026-02-16 qmk/led progress
    [travis-ergogen-2026-leds.xlsx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]
2026-02-19 pin fix
    [travis_erg2026.kicad_pcb]
2026-02-19 symmetry fixes
    [travis_erg2026.kicad_pcb]
2026-02-22 v4, rounded
    [BOM-travis_erg2026-v4-round.csv, bom.csv, designators.csv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]
